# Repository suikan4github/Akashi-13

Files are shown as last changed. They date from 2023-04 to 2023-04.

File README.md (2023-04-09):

# Akashi-13
Ethernet JIG for Nucleo H743ZI2

# Details
This is a LAN9220 ehternet controller board for the Nucleo H743ZI. 

The LAN9220 is accessible through the FMC SRAM configuration NE1. 
The LAN9220 doesn't have READY signal. Thus, the wait cycles should
be set by program appropriately. 

The following signals could be assigned to the interrupt (EXTI).
- PME : PA0
- IRQ : PA4

# Nucleo Pin configurations

The followings are the pin configuration of Nucleo board. 
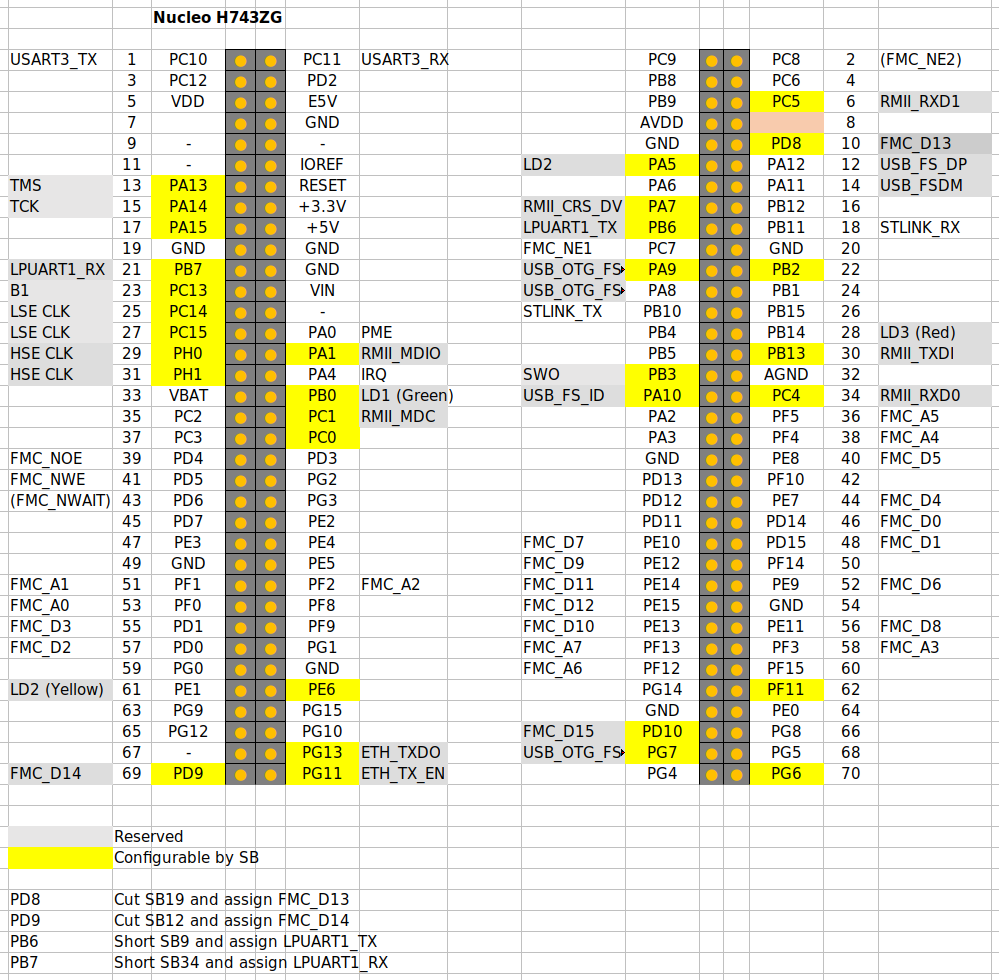
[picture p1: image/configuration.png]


Also, short bridge have to be configured as the followings : 

- PD8 : Cut SB12 to disconnect the STLINK VCOMM signal. 
- PD9 : Cut SB19 to disconnect the STLINK VCOMM signal. 
- PB6 : Short SB9 to assign LPUART1_TX to STLINK VCOMM signal.
- PB7 : Short SB34 to assign LPUART1_TX to STLINK VCOMM signal.

The USART3 is connected to STLINK VCOMM through the PD8 and PD9 by default. 
These pins are re-assigned to FMC. Thus, the LPUART1 have to be connected
to the STLINK VCOMM through the PB6 and PB7. 

PD6 (FMC_NWAIT) and FMC_NE1 (PC7) are not used in this board. 

# License
This project is licensed by the [MIT license](LICENSE). 

# Gallery

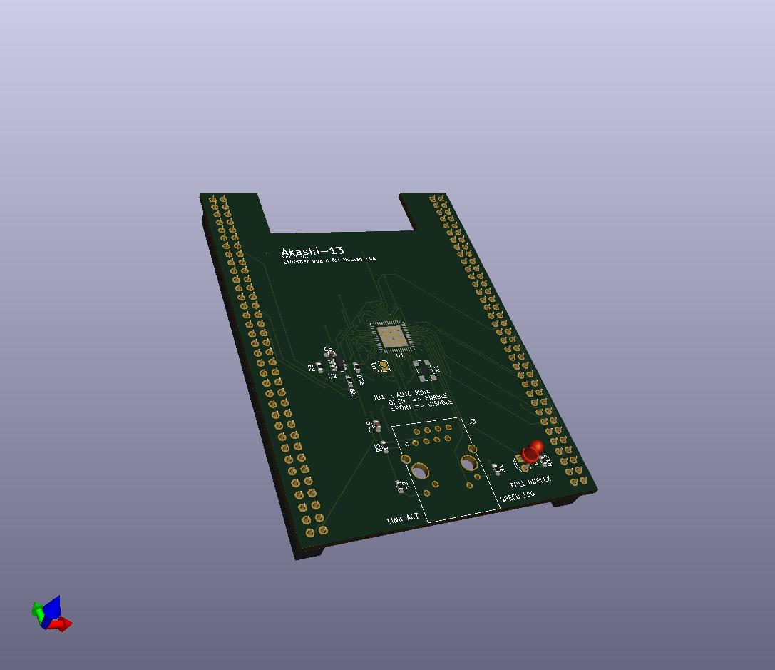
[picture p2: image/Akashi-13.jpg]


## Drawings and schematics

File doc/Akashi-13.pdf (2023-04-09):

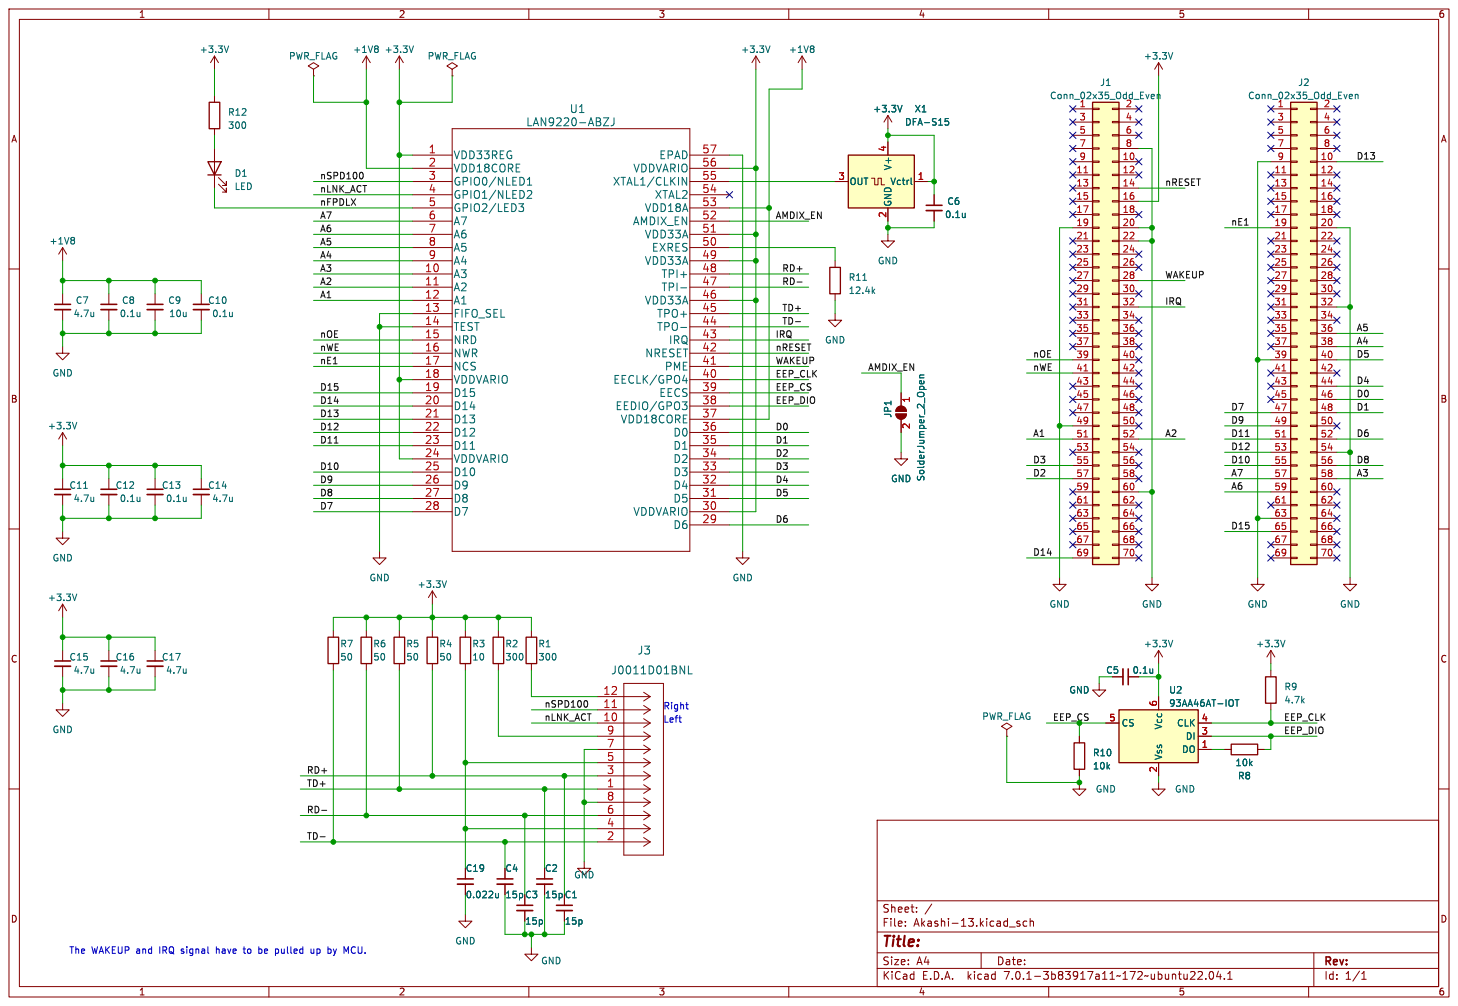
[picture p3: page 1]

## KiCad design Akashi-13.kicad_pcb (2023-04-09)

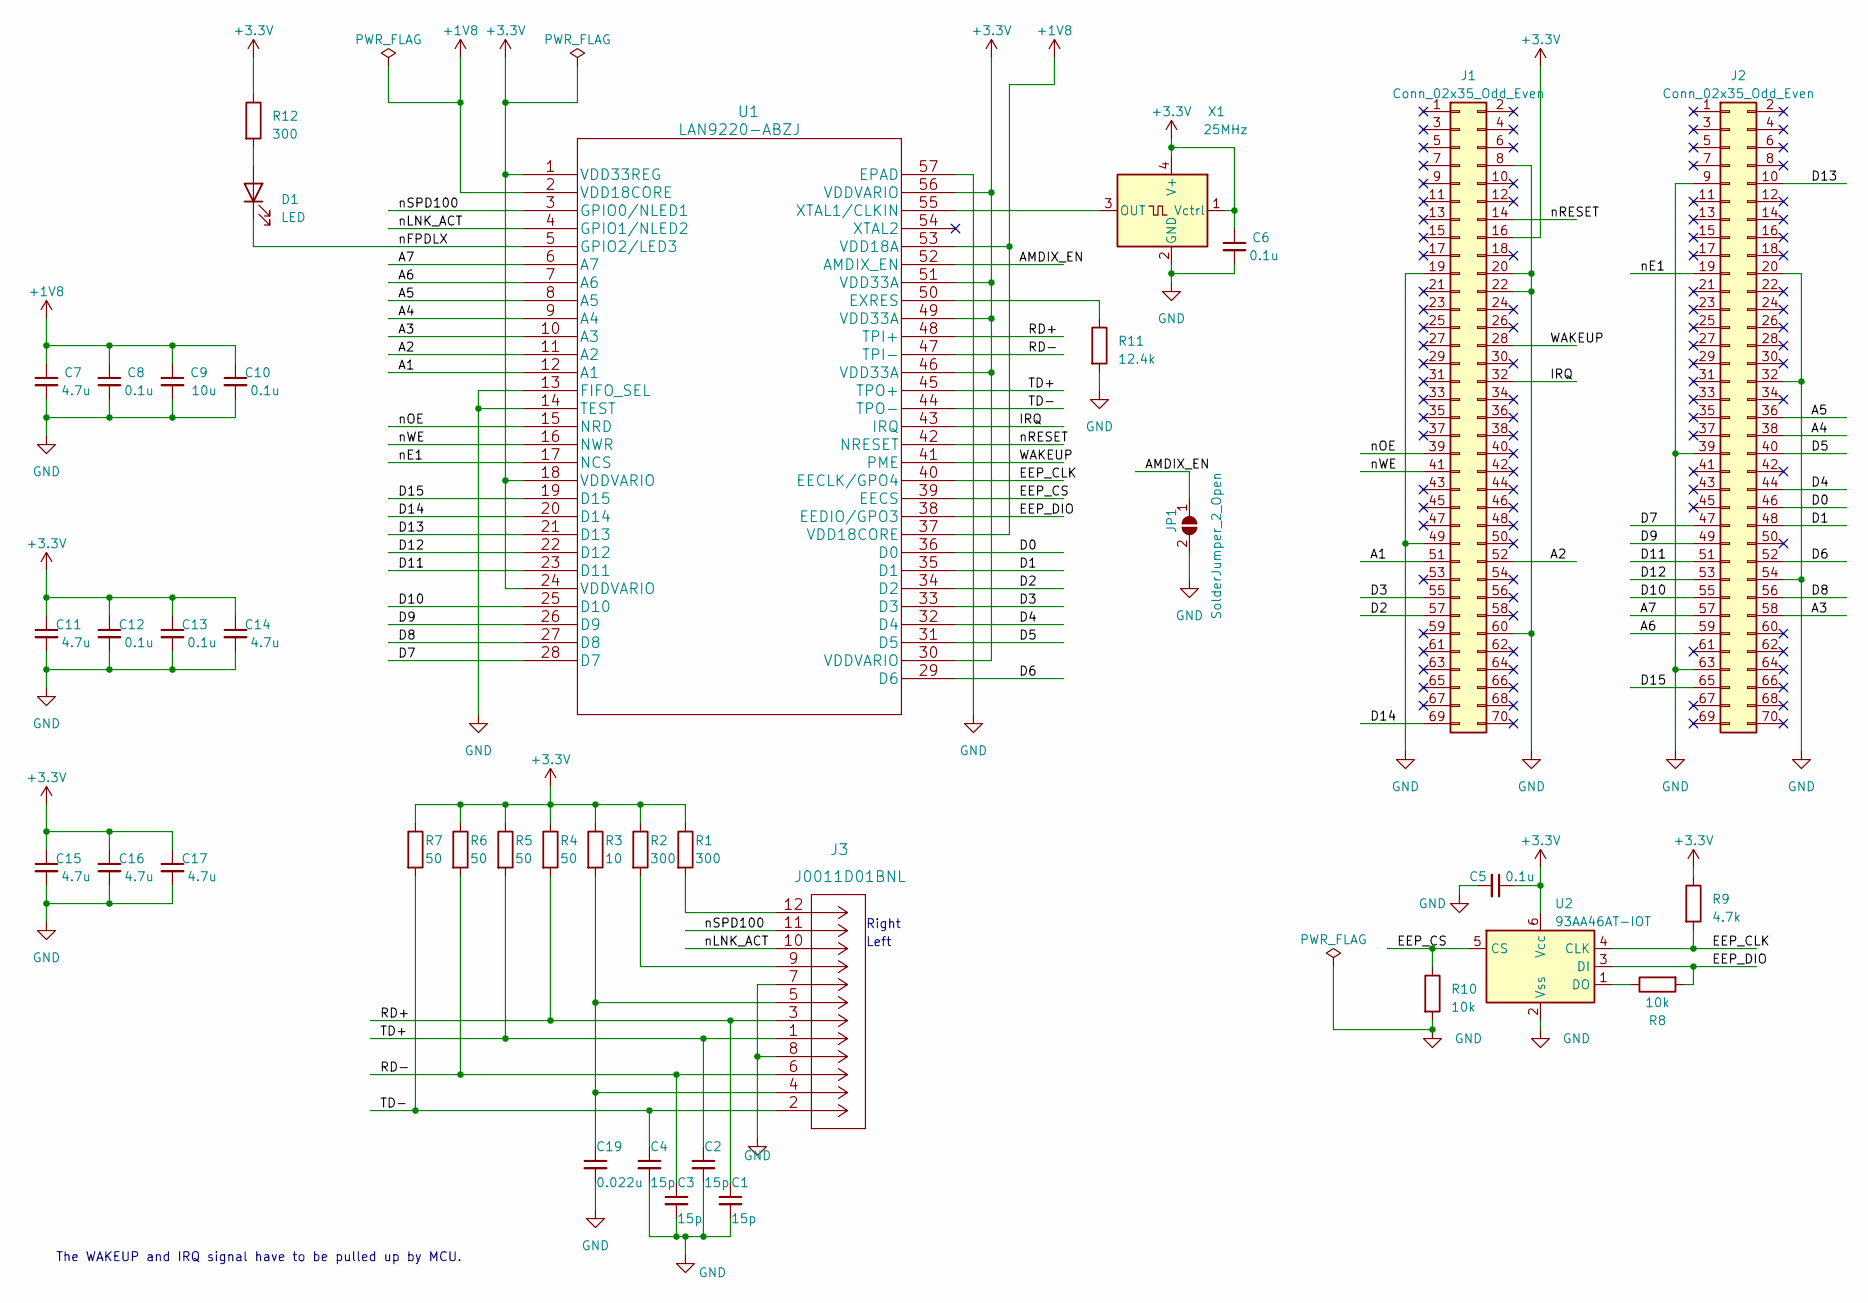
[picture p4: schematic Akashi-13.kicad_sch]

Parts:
C1, C2, C3, C4: 15p; C_0603_1608Metric_Pad1.08x0.95mm_HandSolder
C5, C6, C8, C10, C12, C13: 0.1u; C_0603_1608Metric_Pad1.08x0.95mm_HandSolder
C7, C11, C14, C15, C16, C17: 4.7u; C_0603_1608Metric_Pad1.08x0.95mm_HandSolder
C9: 10u; C_0603_1608Metric_Pad1.08x0.95mm_HandSolder
C19: 0.022u; C_0603_1608Metric_Pad1.08x0.95mm_HandSolder
D1: LED; LED_D3.0mm
J1, J2: Conn_02x35_Odd_Even; PinSocket_2x35_P2.54mm_Vertical
J3: J0011D01BNL
JP1: SolderJumper_2_Open; SolderJumper-2_P1.3mm_Open_TrianglePad1.0x1.5mm
R1, R2, R12: 300; R_0603_1608Metric_Pad0.98x0.95mm_HandSolder
R3: 10; R_0603_1608Metric_Pad0.98x0.95mm_HandSolder
R4, R5, R6, R7: 50; R_0603_1608Metric_Pad0.98x0.95mm_HandSolder
R8, R10: 10k; R_0603_1608Metric_Pad0.98x0.95mm_HandSolder
R9: 4.7k; R_0603_1608Metric_Pad0.98x0.95mm_HandSolder
R11: 12.4k; R_0603_1608Metric_Pad0.98x0.95mm_HandSolder
U1: LAN9220-ABZJ; QFN-56-1EP_8x8mm_P0.5mm_EP5.9x5.9mm
U2: 93AA46AT-IOT; SOT-23-6
X1: 25MHz; Oscillator_SMD_Fordahl_DFAS15-4Pin_5.0x3.2mm

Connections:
+1V8: C7.1, C8.1, C9.1, C10.1, U1.2 (VDD18CORE), U1.37 (VDD18CORE), U1.53 (VDD18A)
+3.3V: C5.1, C6.1, C11.1, C12.1, C13.1, C14.1, C15.1, C16.1, C17.1, J1.16, R1.1, R2.1, R3.1, R4.1, R5.1, R6.1, R7.1, R9.1, R12.1, U1.1 (VDD33REG), U1.18 (VDDVARIO), U1.24 (VDDVARIO), U1.30 (VDDVARIO), U1.46 (VDD33A), U1.49 (VDD33A), U1.51 (VDD33A), U1.56 (VDDVARIO), U2.6 (Vcc), X1.1 (Vctrl), X1.4 (V+)
/A1: J1.51, U1.12 (A1)
/A2: J1.52, U1.11 (A2)
/A3: J2.58, U1.10 (A3)
/A4: J2.38, U1.9 (A4)
/A5: J2.36, U1.8 (A5)
/A6: J2.59, U1.7 (A6)
/A7: J2.57, U1.6 (A7)
/AMDIX_EN: JP1.1 (A), U1.52 (AMDIX_EN)
/D0: J2.46, U1.36 (D0)
/D1: J2.48, U1.35 (D1)
/D2: J1.57, U1.34 (D2)
/D3: J1.55, U1.33 (D3)
/D4: J2.44, U1.32 (D4)
/D5: J2.40, U1.31 (D5)
/D6: J2.52, U1.29 (D6)
/D7: J2.47, U1.28 (D7)
/D8: J2.56, U1.27 (D8)
/D9: J2.49, U1.26 (D9)
/D10: J2.55, U1.25 (D10)
/D11: J2.51, U1.23 (D11)
/D12: J2.53, U1.22 (D12)
/D13: J2.10, U1.21 (D13)
/D14: J1.69, U1.20 (D14)
/D15: J2.65, U1.19 (D15)
/EEP_CLK: R9.2, U1.40 (EECLK/GPO4), U2.4 (CLK)
/EEP_CS: R10.1, U1.39 (EECS), U2.5 (CS)
/EEP_DIO: R8.2, U1.38 (EEDIO/GPO3), U2.3 (DI)
/IRQ: J1.32, U1.43 (IRQ)
/RD+: C1.1, J3.3, R4.2, U1.48 (TPI+)
/RD-: C3.1, J3.6, R6.2, U1.47 (TPI-)
/TD+: C2.1, J3.1, R5.2, U1.45 (TPO+)
/TD-: C4.1, J3.2, R7.2, U1.44 (TPO-)
/WAKEUP: J1.28, U1.41 (PME)
/nE1: J2.19, U1.17 (NCS)
/nFPDLX: D1.1 (K), U1.5 (GPIO2/LED3)
/nLNK_ACT: J3.10, U1.4 (GPIO1/NLED2)
/nOE: J1.39, U1.15 (NRD)
/nRESET: J1.14, U1.42 (NRESET)
/nSPD100: J3.11, U1.3 (GPIO0/NLED1)
/nWE: J1.41, U1.16 (NWR)
GND: C1.2, C2.2, C3.2, C4.2, C5.2, C6.2, C7.2, C8.2, C9.2, C10.2, C11.2, C12.2, C13.2, C14.2, C15.2, C16.2, C17.2, C19.2, J1.8, J1.19, J1.20, J1.22, J1.49, J1.60, J2.9, J2.20, J2.32, J2.39, J2.54, J2.63, J3.7, J3.8, J3.15, J3.16, JP1.2 (B), R10.2, R11.2, U1.13 (FIFO_SEL), U1.14 (TEST), U1.57 (EPAD), U2.2 (Vss), X1.2 (GND)
unnamed: C19.1, J3.4, J3.5, R3.2
unnamed: D1.2 (A), R12.2
unnamed: J3.9, R2.2
unnamed: J3.12, R1.2
unnamed: R11.1, U1.50 (EXRES)
unnamed: U1.55 (XTAL1/CLKIN), X1.3 (OUT)
unnamed: R8.1, U2.1 (DO)

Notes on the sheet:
Right
The WAKEUP and IRQ signal have to be pulled up by MCU.
Left

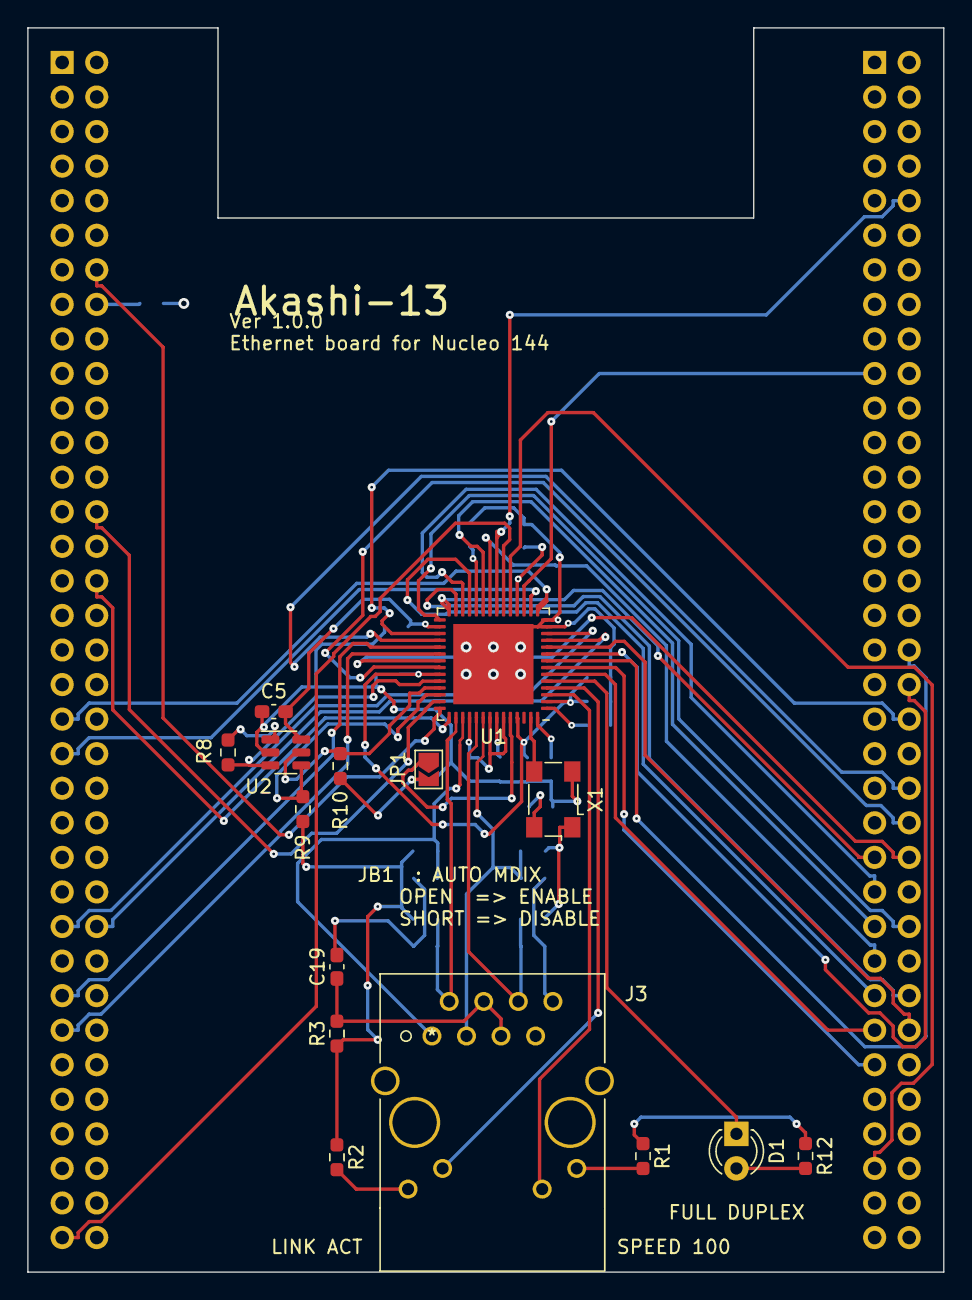
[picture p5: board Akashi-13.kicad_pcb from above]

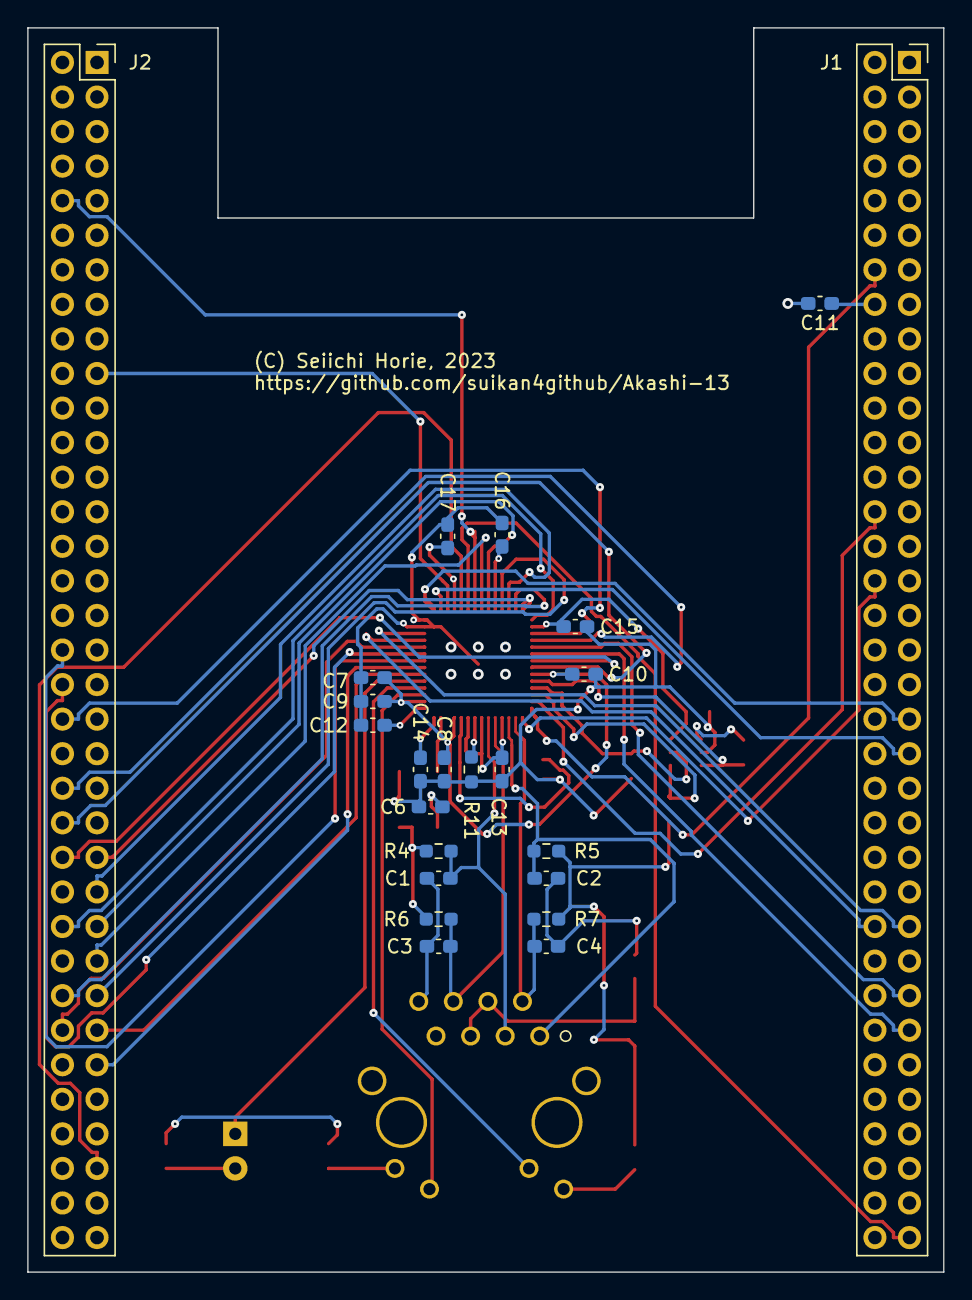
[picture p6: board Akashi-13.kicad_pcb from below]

Board: 4 copper layers, 67.3 x 91.4 mm, 38 parts (23 on the bottom side), 50 nets.

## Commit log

2023-03-21 Drawing schematics.
    Done round the RF-45 connectors.
    Connecting the power of the LAN9220.
    [Akashi-13.kicad_pcb, Akashi-13.kicad_sch]
2023-03-21 Added EEPROM
    [Akashi-13.kicad_sch]
2023-03-23 ST Link VCOM changed. IRQ/WAKE UP changed.
    ST LINK vcom are moved from USART3 to LPUART1
    Now, we don't need extra wireling.
    Alternatively, short bridged of the baord have to be modified.
    IQR/WAKEUP pins are moved. Now. we can cut two extra pins of
    morpho connectors to reduce the pin force.
    [Akashi-13.kicad_pcb, Akashi-13.kicad_sch, nucleo-h743zi-pin-assign.ods]
2023-03-23 Finished to input schematics.
    ERC OK.
    [Akashi-13.kicad_pcb, Akashi-13.kicad_sch]
2023-03-23 All bypass chapacitor of LAN9220 and XTAL are placed.
    [Akashi-13.kicad_pcb, Akashi-13.kicad_sch]
2023-03-24 Placed all parts
    [Akashi-13.kicad_pcb]
2023-03-24 Fixed wrong courtyard of the J3.
    Ready to autoroute.
    [Akashi-13.kicad_pcb]
2023-03-24 in the middle of routing
    [Akashi-13.kicad_pcb]
2023-03-25 Layout done.
    [Akashi-13.kicad_pcb]
2023-03-25 Set shield pins of the Mojular Jack to GND.
    [Akashi-13.kicad_pcb]
2023-03-25 Add comment on the board.
    JB1
    LEDs
    [Akashi-13.kicad_pcb, Akashi-13.kicad_sch, nucleo-h743zi-pin-assign.ods]
2023-03-26 Write README.
    [nucleo-h743zi-pin-assign.ods]
2023-03-26 Print the schematics and Gerber.
    [Akashi-13-B_Cu.gbr, Akashi-13-B_Mask.gbr, Akashi-13-B_Paste.gbr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]
2023-04-09 Add vias to the exposed pad of U1.
    Also following FusionPCB rules.
    [Akashi-13-B_Cu.gbr, Akashi-13-B_Mask.gbr, Akashi-13-B_Paste.gbr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]
2023-04-09 Add version number to sylkscreen
    [Akashi-13-B_Cu.gbr, Akashi-13-B_Mask.gbr, Akashi-13-B_Silkscreen.gbr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]
2023-04-09 Add board 3D view.

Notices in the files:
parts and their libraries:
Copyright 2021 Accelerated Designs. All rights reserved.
